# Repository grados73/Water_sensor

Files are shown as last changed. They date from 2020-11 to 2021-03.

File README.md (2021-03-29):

# Project Name
> Water ESP Sensor

## Table of contents
* [General info](#general-info)
* [Screenshots](#screenshots)
* [Technologies](#technologies)
* [Features](#features)
* [Status](#status)
* [Inspiration](#inspiration)
* [Contact](#contact)

## General info
When I put the almost 600l aquarium in my flat, my wife was afraid of flooding the apartment. To calm her down I designed, programmed and made my own PCB with ESP8266.
The device, if it detects water on any of the two connected sensors, sends messages via a Telegram app and generate sound signal.

## Screenshots
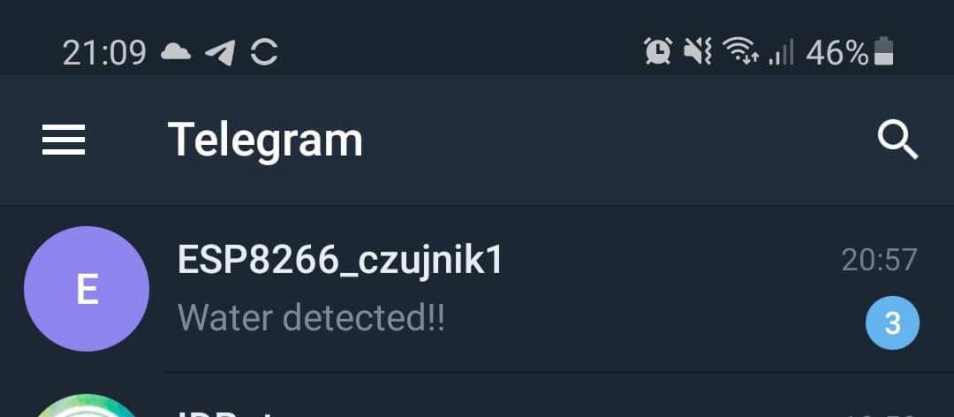
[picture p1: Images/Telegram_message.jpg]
Message

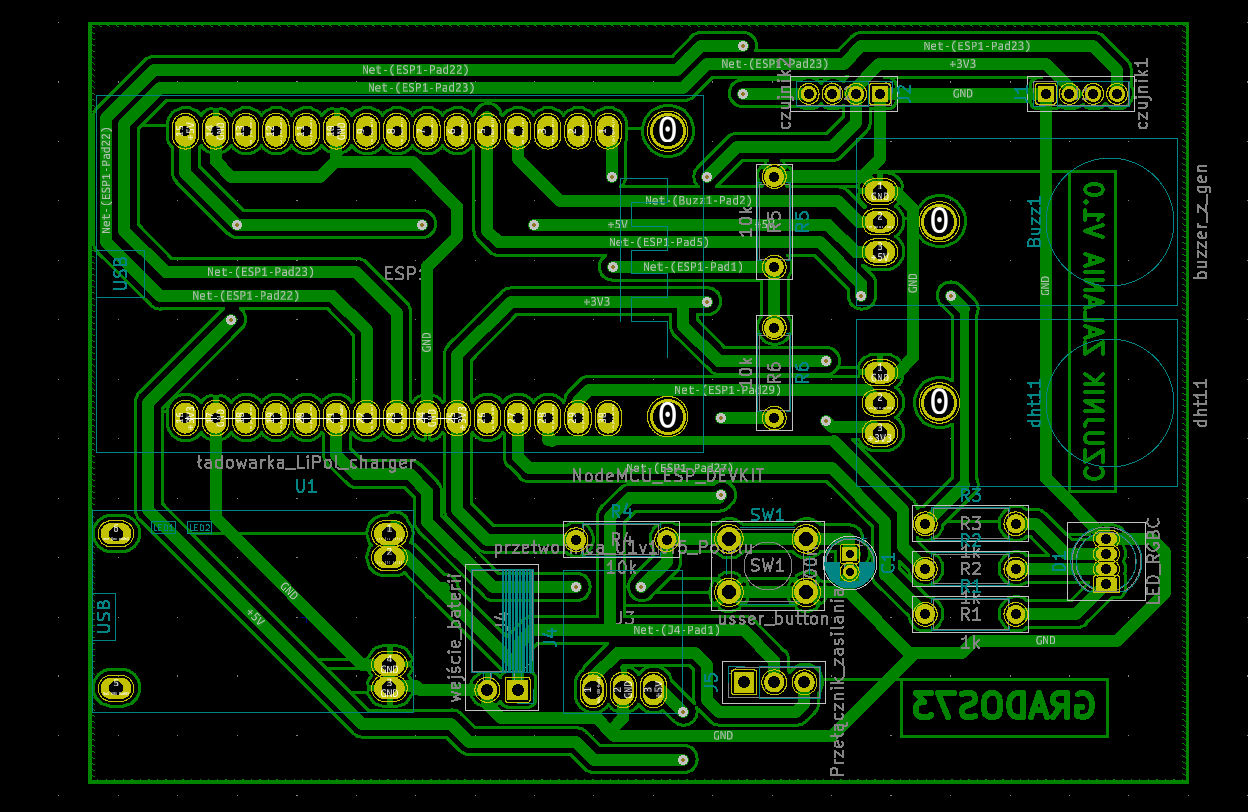
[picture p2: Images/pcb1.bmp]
PCB2

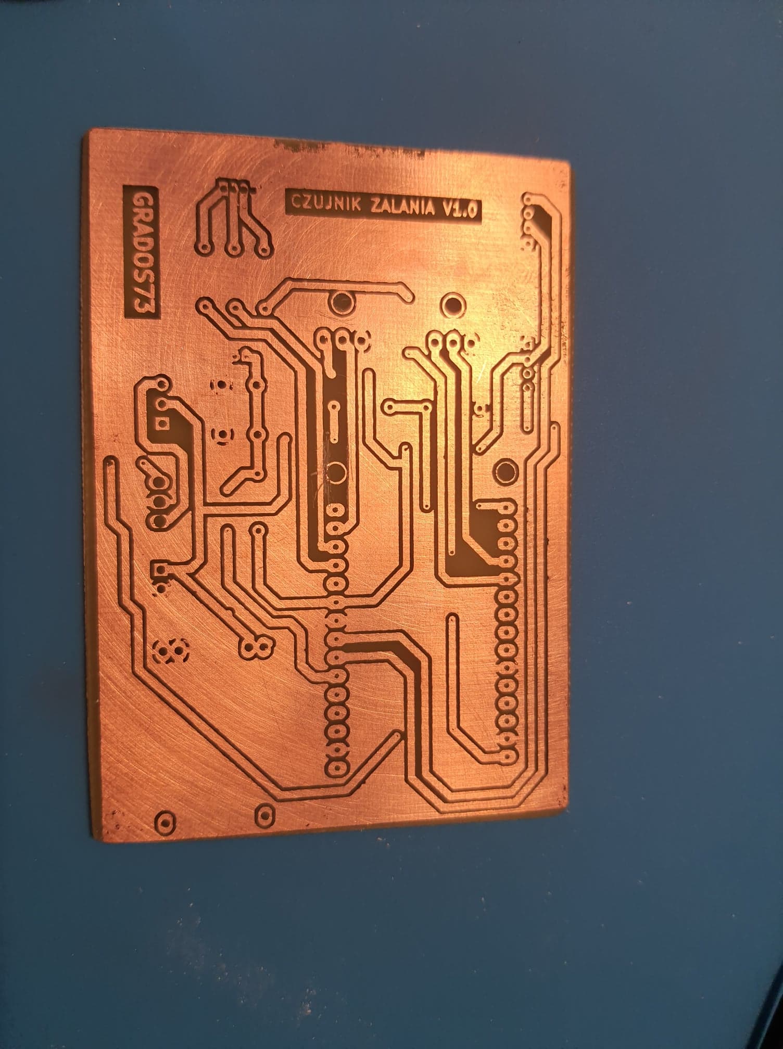
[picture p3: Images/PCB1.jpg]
PCB


## Technologies
C,
Arduino IDE.

## Features
-Send message via a Telegram when detect water,
-When asked, he replies informing us about the temperature, air humidity and battery voltage.

To-do list:
* Low battery level alarm.

## Status
It is working, maybe someday I will do v.1.1.

## Inspiration
Commercial devices are expensive or have limited features.

## Contact
Created by https://www.linkedin.com/in/kamil-gradowski-8706991aa - feel free to contact me!
grados73

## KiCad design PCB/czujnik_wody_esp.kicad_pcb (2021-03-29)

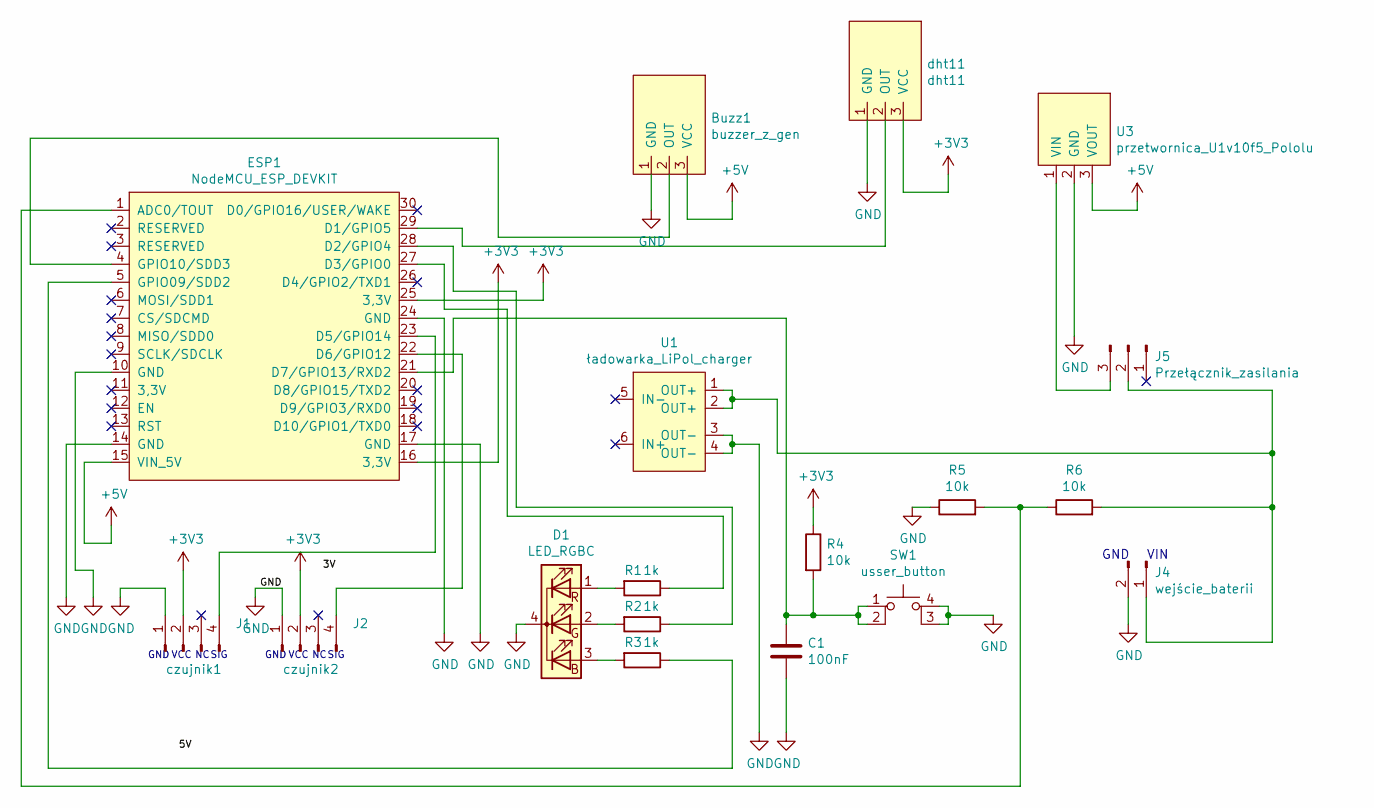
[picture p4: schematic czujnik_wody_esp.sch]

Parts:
Buzz1: buzzer_z_gen
C1: 100nF; CP_Radial_D4.0mm_P1.50mm
D1: LED_RGBC; LED_D5.0mm-4_RGB
ESP1: NodeMCU_ESP_DEVKIT; devkit1.0_NodeMCU_esp
J1: czujnik1; PinHeader_1x04_P2.00mm_Vertical
J2: czujnik2; PinHeader_1x04_P2.00mm_Vertical
J4: wejście_baterii; PinSocket_1x02_P2.54mm_Horizontal
J5: Przełącznik_zasilania; PinSocket_1x03_P2.54mm_Vertical
R1, R2, R3: 1k; R_Axial_DIN0207_L6.3mm_D2.5mm_P7.62mm_Horizontal
R4, R5, R6: 10k; R_Axial_DIN0207_L6.3mm_D2.5mm_P7.62mm_Horizontal
SW1: usser_button; SW_PUSH_6mm_H5mm
U1: ładowarka_LiPol_charger
U3: przetwornica_U1v10f5_Pololu; przetwornica_u1v10f5_pololu
dht11: dht11; buzzer_z_gen

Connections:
+3V3: ESP1.16 (3,3V), ESP1.25 (3,3V), J1.2, J2.2, R4.1, dht11.3 (VCC)
+5V: Buzz1.3 (VCC), ESP1.15 (VIN_5V), U3.3 (VOUT)
GND: Buzz1.1 (GND), C1.2, D1.4 (K), ESP1.10 (GND), ESP1.14 (GND), ESP1.17 (GND), ESP1.24 (GND), J1.1, J2.1, J4.2, R5.1, SW1.3 (K), SW1.4 (A), U1.3 (OUT-), U1.4 (OUT-), U3.2 (GND), dht11.1 (GND)
unnamed: Buzz1.2 (OUT), ESP1.4 (GPIO10/SDD3)
unnamed: C1.1, ESP1.21 (D7/GPIO13/RXD2), R4.2, SW1.1, SW1.2
unnamed: D1.1 (RA), R1.2
unnamed: D1.2 (GA), R2.2
unnamed: D1.3 (BA), R3.2
unnamed: ESP1.1 (ADC0/TOUT), R5.2, R6.1
unnamed: ESP1.5 (GPIO09/SDD2), R3.1
unnamed: ESP1.22 (D6/GPIO12), J2.4
unnamed: ESP1.23 (D5/GPIO14), J1.4
unnamed: ESP1.27 (D3/GPIO0), R1.1
unnamed: ESP1.28 (D2/GPIO4), R2.1
unnamed: ESP1.29 (D1/GPIO5), dht11.2 (OUT)
unnamed: J4.1, J5.2, R6.2, U1.1 (OUT+), U1.2 (OUT+)
unnamed: J5.3, U3.1 (VIN)

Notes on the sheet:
VIN
GND
GND
VCC
SIG

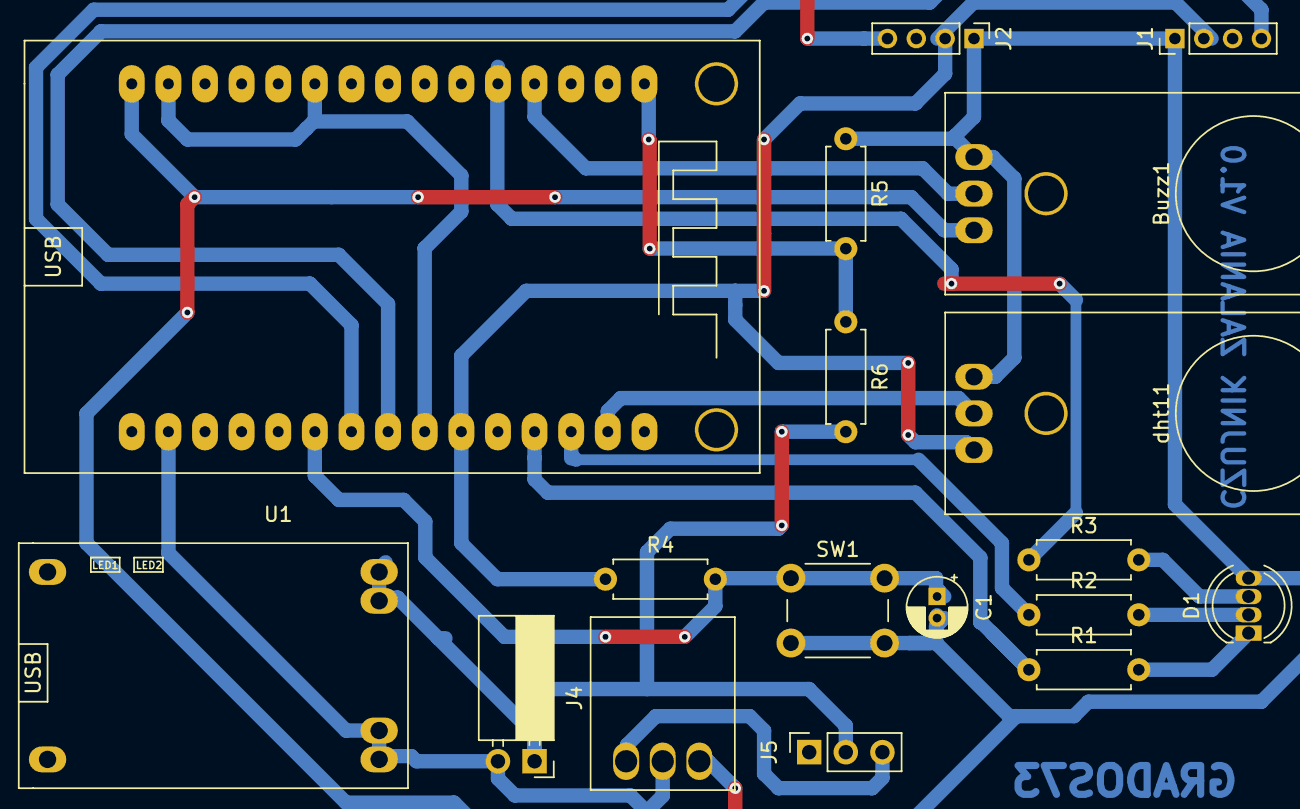
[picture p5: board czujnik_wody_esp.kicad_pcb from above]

Board: 2 copper layers, 18 parts (0 on the bottom side), 17 nets.

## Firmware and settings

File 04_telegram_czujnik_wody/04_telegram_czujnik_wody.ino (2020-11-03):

/*
Author:Grad73
*/

#include <ESP8266WiFi.h>
#include <WiFiClientSecure.h>
#include <UniversalTelegramBot.h>
#include <ArduinoJson.h>
#include "DHT.h"

// DANE LOGOWANIA DO WIFI!
    const char* ssid = "internet_kamil";
    const char* password = "gradowscyc";

// Initialize Telegram BOT
    #define BOTtoken "1475983679:AAGvv_-sYh6N0-zjY40F8Y3xmen_mH0tBaw"  // your Bot Token (Get from Botfather)

// Moje ID od @myidbot 
    #define CHAT_ID "948004899"

//Inicjalizacja czujnika DHT
    #define DHTTYPE DHT11   // DHT 11
    #define DHTPIN 5     // Digital pin connected to the DHT sensor
    DHT dht(DHTPIN, DHTTYPE);// Initialize DHT sensor.

//Buzzer alarmowy
    #define BUZZERPIN 10

//ADC 
    const int analogInPin = A0; 
    int sensorValue = 0;  // value read from the pot
    int outputValue = 0;  // value to output to a PWM pin   
    
//Stworzenie nowego klienta WiFi
    WiFiClientSecure client;
//Stworzenie nowego bota
    UniversalTelegramBot bot(BOTtoken, client);

// Interwał czasowy co jaki ESP sprawdza czy otrzymało wiadomość z Telegrama w [ms] 1000 [ms] = 1[s]
    int botRequestDelay = 1000;
    unsigned long lastTimeBotRan;

//Pin do którego jest podłączony sensor wody i flaga od wykrycia wody
    const int waterSensor = 14; // 
    bool waterDetected = false;
    
    int flagaAlarm = 0; // podnoszona jest po wykryciu wody
    unsigned long previousMillis = 0; // zmienna zapisujaca czas wykrycia wody
    int dlugoscAlarmu = 2000; // czas w [ms] jak dlugo ma trwac alarm po wykryciu wody

// Indicates when motion is detected
    void ICACHE_RAM_ATTR detectsWater() {
      //Serial.println("WATER DETECTED!!!");
      waterDetected = true;
}

void setup() {
  Serial.begin(115200);
  client.setInsecure();
  //Dioda wbudowana sygnalizuje wykrycie wody
  pinMode(LED_BUILTIN, OUTPUT);  
  digitalWrite(LED_BUILTIN, HIGH);
  //Buzzer
  pinMode(BUZZERPIN, OUTPUT);  
  digitalWrite(BUZZERPIN, HIGH);

  //DHT wlaczenie czujnika
   dht.begin();

  // water Sensor mode INPUT_PULLUP
  pinMode(waterSensor, INPUT_PULLUP);
  // Set waterSensor pin as interrupt, assign interrupt function and set RISING mode
  attachInterrupt(digitalPinToInterrupt(waterSensor), detectsWater, FALLING);

  // Attempt to connect to Wifi network:
  Serial.print("Connecting Wifi: ");
  Serial.println(ssid);

  WiFi.mode(WIFI_STA);
  WiFi.begin(ssid, password);

  while (WiFi.status() != WL_CONNECTED) {
    Serial.print(".");
    delay(500);
  }

  Serial.println("");
  Serial.println("WiFi connected");
  Serial.print("IP address: ");
  Serial.println(WiFi.localIP());

  bot.sendMessage(CHAT_ID, "Bot started up", "");
}

void loop() {

unsigned long currentMillis = millis();

// SPRAWDZA CZY SA NOWE WIAODMOSCI CO botRequestDelay (1s)
    if (millis() > lastTimeBotRan + botRequestDelay)  {
        int numNewMessages = bot.getUpdates(bot.last_message_received + 1);
        while(numNewMessages) {
          Serial.println("got response");
          handleNewMessages(numNewMessages);
          numNewMessages = bot.getUpdates(bot.last_message_received + 1);
        }
        lastTimeBotRan = millis();
      }
// JEŚLI WYKRYTO WODE NA SENSORZE
    if(waterDetected){
        bot.sendMessage(CHAT_ID, "Water detected!!", "");
        Serial.println("Water Detected");
        digitalWrite(LED_BUILTIN, LOW); 
        digitalWrite(BUZZERPIN, LOW);
        waterDetected = false;
        previousMillis = currentMillis;
        flagaAlarm =1;
    }

// WYLACZANIE ALARMU PO CZASIE dlugoscAlarmu
   if(flagaAlarm == 1){
       if (currentMillis - previousMillis >= dlugoscAlarmu) {
          digitalWrite(LED_BUILTIN, HIGH);
          digitalWrite(BUZZERPIN, HIGH);
          flagaAlarm = 0; 
        }
   }

}

//###################### FUNKCJE ######################
//Zczytuje temperature i wilgotność z DHT11 i zwraca w formie stringa, którego możemy wysłać Telgramem
String getReadings(){
  float h = dht.readHumidity();
  float t = dht.readTemperature();
  float v = analogRead(analogInPin)/166;
  String message = "Temperatura: " + String(t) + " ºC \n";
  message += "Wilgotnosc: " + String (h) + " % \n";
  message += "Napiecie zasilania:: " + String (v) + " V \n";
  return message;
}

//Funkcja do obslugi otrzymanych wiaodmosci
void handleNewMessages(int numNewMessages) {
  Serial.println("handleNewMessages");
  Serial.println(String(numNewMessages));

  for (int i=0; i<numNewMessages; i++) { // sprawdza osiagalnosc wiadomosci
    // Chat id of the requester
    String chat_id = String(bot.messages[i].chat_id); //sprawdza id od kogo ta wiadomosc przyszla i czy jest to wiadomosc od nas
    if (chat_id != CHAT_ID){ // wiadomosc od kogos obcego, ignoruje
      bot.sendMessage(chat_id, "Unauthorized user", "");
      continue;
    }
    // jesli jest to wiadomosc od autoryzowanego uzytkownika to zapisuje ja do zmiennej text
    // Print the received message
    String text = bot.messages[i].text;
    Serial.println(text);

    String from_name = bot.messages[i].from_name; // zapisuje od kogo otrzymal wiadomosc

    if (text == "/start") {
      String welcome = "Welcome, " + from_name + ".\n";
      welcome += "Use the following command to get current readings.\n\n";
      welcome += "/readings \n";
      bot.sendMessage(chat_id, welcome, "");
    }

    if (text == "/readings") {
      String readings = getReadings();
      bot.sendMessage(chat_id, readings, "");
    }  
  }
}

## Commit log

2020-11-03 działa DHT11, dziala telegram request o temperature i wilgotnosc
2020-11-03 dziala buzzer i dioda jako alarm
    [04_telegram_czujnik_wody.ino]
2021-03-29 Add PCB project
    [czujnik_wody_esp.kicad_pcb, czujnik_wody_esp.sch]
2021-03-29 Add PCB img1
2021-03-29 Add KiCad PCB photo
